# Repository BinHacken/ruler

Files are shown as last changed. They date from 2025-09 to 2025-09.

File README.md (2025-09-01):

# PCB Ruler "Bright Start"

Ein Platinen Lineal für die Ersti-Tüte der TH Bingen 2025. 
Mit kleinen cheat-sheets für die Informatik Studierenden.

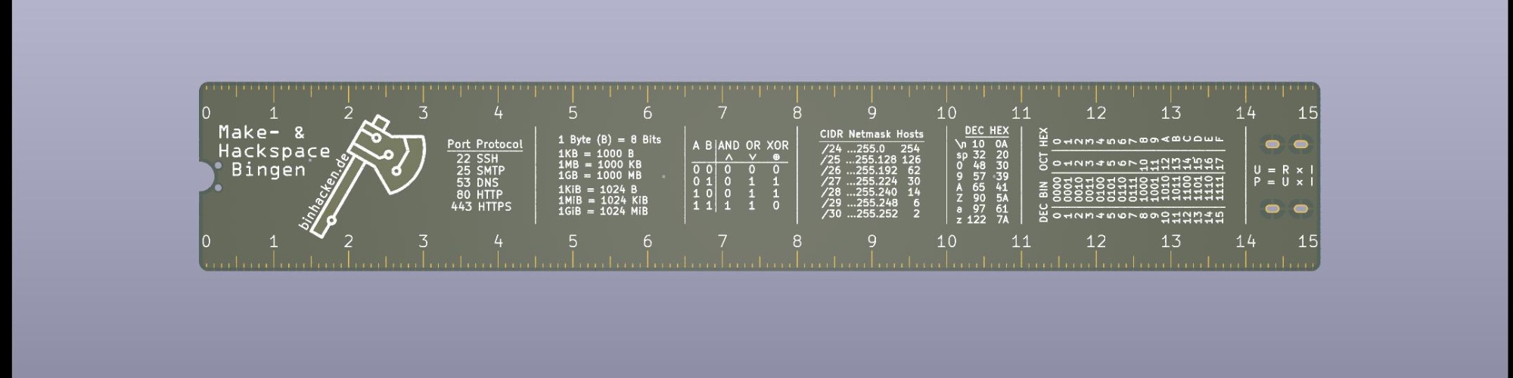
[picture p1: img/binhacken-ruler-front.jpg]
Front Side of PCB Ruler

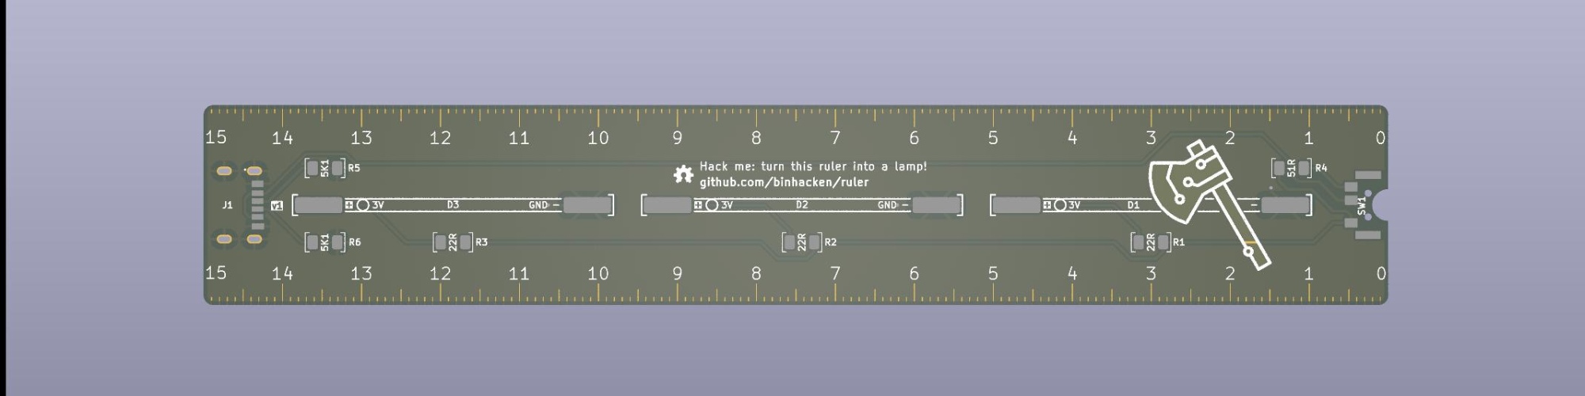
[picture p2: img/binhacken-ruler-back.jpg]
Back Side of PCB Ruler


Kann zu einer LED Lampe umgebaut werden. 

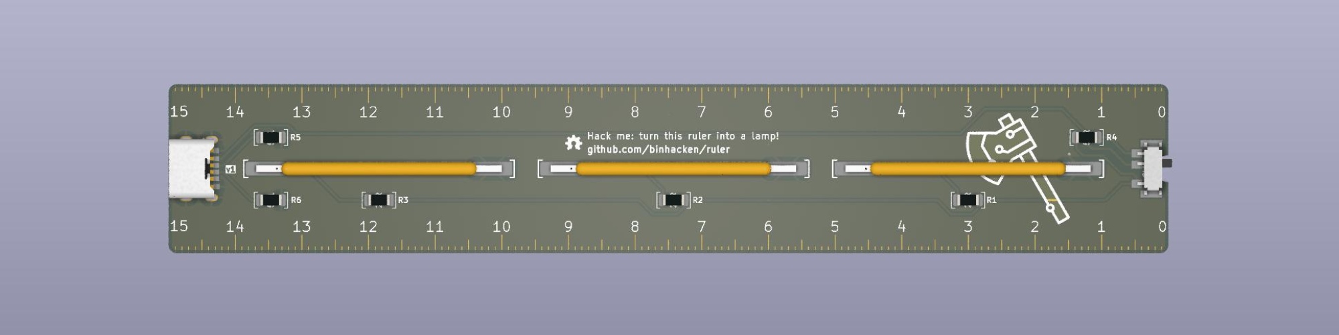
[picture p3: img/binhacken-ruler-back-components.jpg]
Back Side of PCB Ruler with components


## Components

- PCB (Das Lineal selbst)
- 3x LED Filament 3V 38mm (D1,D2,D3)
- 1x USB-C Buchse 6-Pin (J1)
- 6x Wiederstände 1206
    - 3x 22Ω (R1,R2,R3)
    - 1x 51Ω (R4)
    - 2x 5.1KΩ (R5,R6)
- 1x 7pin toggle switch (SW1)

Für R1,R2,R3 und R4 können auch höhere Widerstandswerte verwendet werden, um die Helligkeit zu verringern. 
R5 und R6 sind für USB und sollten 5.1KΩ haben (im Notfall gehen auch 4.7KΩ – 5.6KΩ). 

Der Schalter (SW1) ist dafür da zwischen 2 Helligkeitsstufen zu wählen. 
Wer stattdessen einen an/aus Schalter bevorzugt, kann R4 weglassen. 

Wir haben die passenden Bauteile und Werkzeug parat, komm gerne vorbei! https://binhacken.de/ 

## Placement

Es empfiehlt sich, die Bauteile wie folgt auf der Platine zu platzieren:

1. Die USB-C Buchse (**J1**) und der 7pin toggle switch (**SW1**). 
2. Die Widerstände (R1-R6)
3. Die LEDs (D1-D3)

Wer wenig Erfahrung mit Löten hat, kann auch gerne mit einem der Widerstände (R1-R6) beginnen, da diese in der Regel einfacher zu löten sind. Auch wenn die USB-C Buchse und der Schalter etwas anspruchsvoller zu löten sind, sollten sie nicht zuletzt platziert werden, da die kleinen Pads sonst schwerer zugänglich sind.

Eine Interaktive Ansicht der Platine gibt es hier: https://htmlpreview.github.io/?https://github.com/BinHacken/ruler/blob/main/bom/ibom.html

## Ordering

Folgende Optionen haben wir bei JLC gewählt:

* Deburring/Edge rounding: Yes
* PCB Thickness: 1mm
* Surface Finish: Leadfree HASL
* Mark on PCB: Remove Mark

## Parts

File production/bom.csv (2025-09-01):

Designator | Footprint | Quantity | Value | LCSC Part #
D1, D2, D3 | LED_Filament_38mm | 3 | LED
J1 | TYPE-C-SMD_TYPE-C-6P | 1 | TYPE-C 6P | C456012
R1, R2, R3 | 1206 | 3 | 22R
R4 | 1206 | 1 | 51R
R5, R6 | 1206 | 2 | 5K1
SW1 | SW-SMD_3P-P1.50_L2.7-W6.6 | 1 | SK-3296S-01-L1 | C319020

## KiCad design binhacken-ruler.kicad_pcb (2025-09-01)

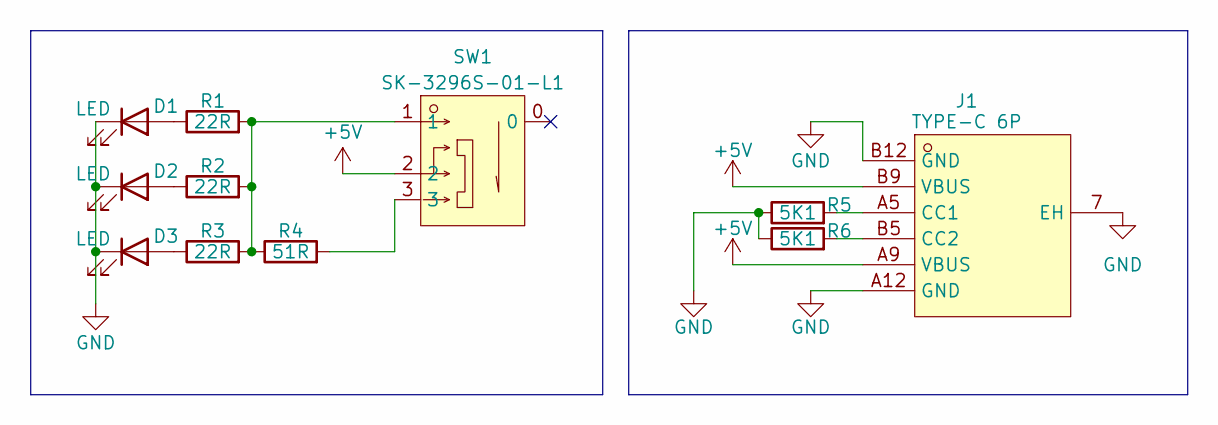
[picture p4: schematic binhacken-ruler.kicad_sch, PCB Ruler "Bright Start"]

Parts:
D1, D2, D3: LED; LED_Filament_38mm
J1: TYPE-C 6P; TYPE-C-SMD_TYPE-C-6P; LCSC Part C456012
R1, R2, R3: 22R; R_1206_3216Metric_Pad1.30x1.75mm_HandSolder
R4: 51R; R_1206_3216Metric_Pad1.30x1.75mm_HandSolder
R5, R6: 5K1; R_1206_3216Metric_Pad1.30x1.75mm_HandSolder
SW1: SK-3296S-01-L1; SW-SMD_3P-P1.50_L2.7-W6.6; LCSC Part C319020

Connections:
+5V: J1.A9 (VBUS), J1.B9 (VBUS), SW1.2
GND: D1.1 (K), D2.1 (K), D3.1 (K), J1.7 (EH), J1.A12 (GND), J1.B12 (GND), R5.1, R6.1
unnamed: D1.2 (A), R1.1
unnamed: D2.2 (A), R2.1
unnamed: D3.2 (A), R3.1
unnamed: R1.2, R2.2, R3.2, R4.1, SW1.1
unnamed: R4.2, SW1.3
unnamed: J1.A5 (CC1), R5.2
unnamed: J1.B5 (CC2), R6.2

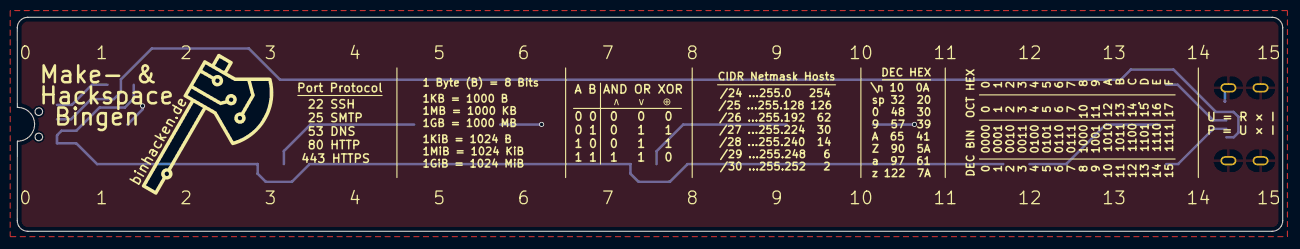
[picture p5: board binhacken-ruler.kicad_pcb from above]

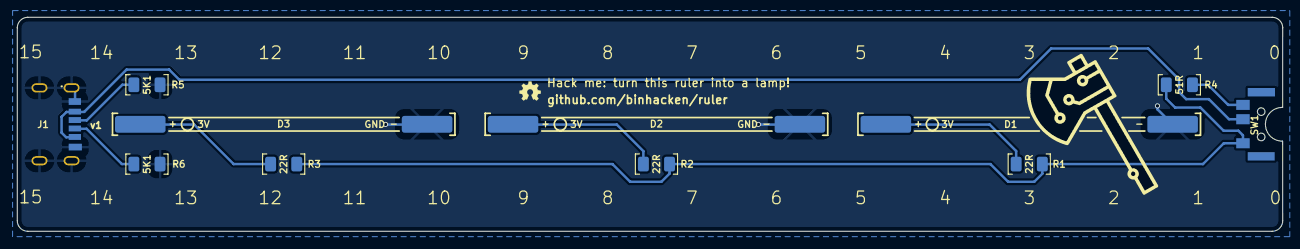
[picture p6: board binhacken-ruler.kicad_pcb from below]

Board: 2 copper layers, 150.0 x 25.4 mm, 11 parts (11 on the bottom side), 9 nets.
